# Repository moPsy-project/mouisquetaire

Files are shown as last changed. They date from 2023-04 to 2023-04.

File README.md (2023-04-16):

# Mousquetaire Eurorack Module

> Eurorack Synthesizer module for Audio/CV Adder and Buffered Multiple

## Dependencies

This project uses symbols from the [moPsy-KiCad-resources](https://github.com/moPsy-project/moPsy-KiCad-resources).

## License



This work is licensed under a [Creative Commons Attribution-ShareAlike 4.0 International License](http://creativecommons.org/licenses/by-sa/4.0/).

BY: Stefan Haun (mail@tuxathome.de)

See [LICENSE.txt](LICENSE.txt) for details.

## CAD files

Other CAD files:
Frontpanel/mousquetaire-outline.FCStd
Frontpanel/mousquetaire-outline.dxf

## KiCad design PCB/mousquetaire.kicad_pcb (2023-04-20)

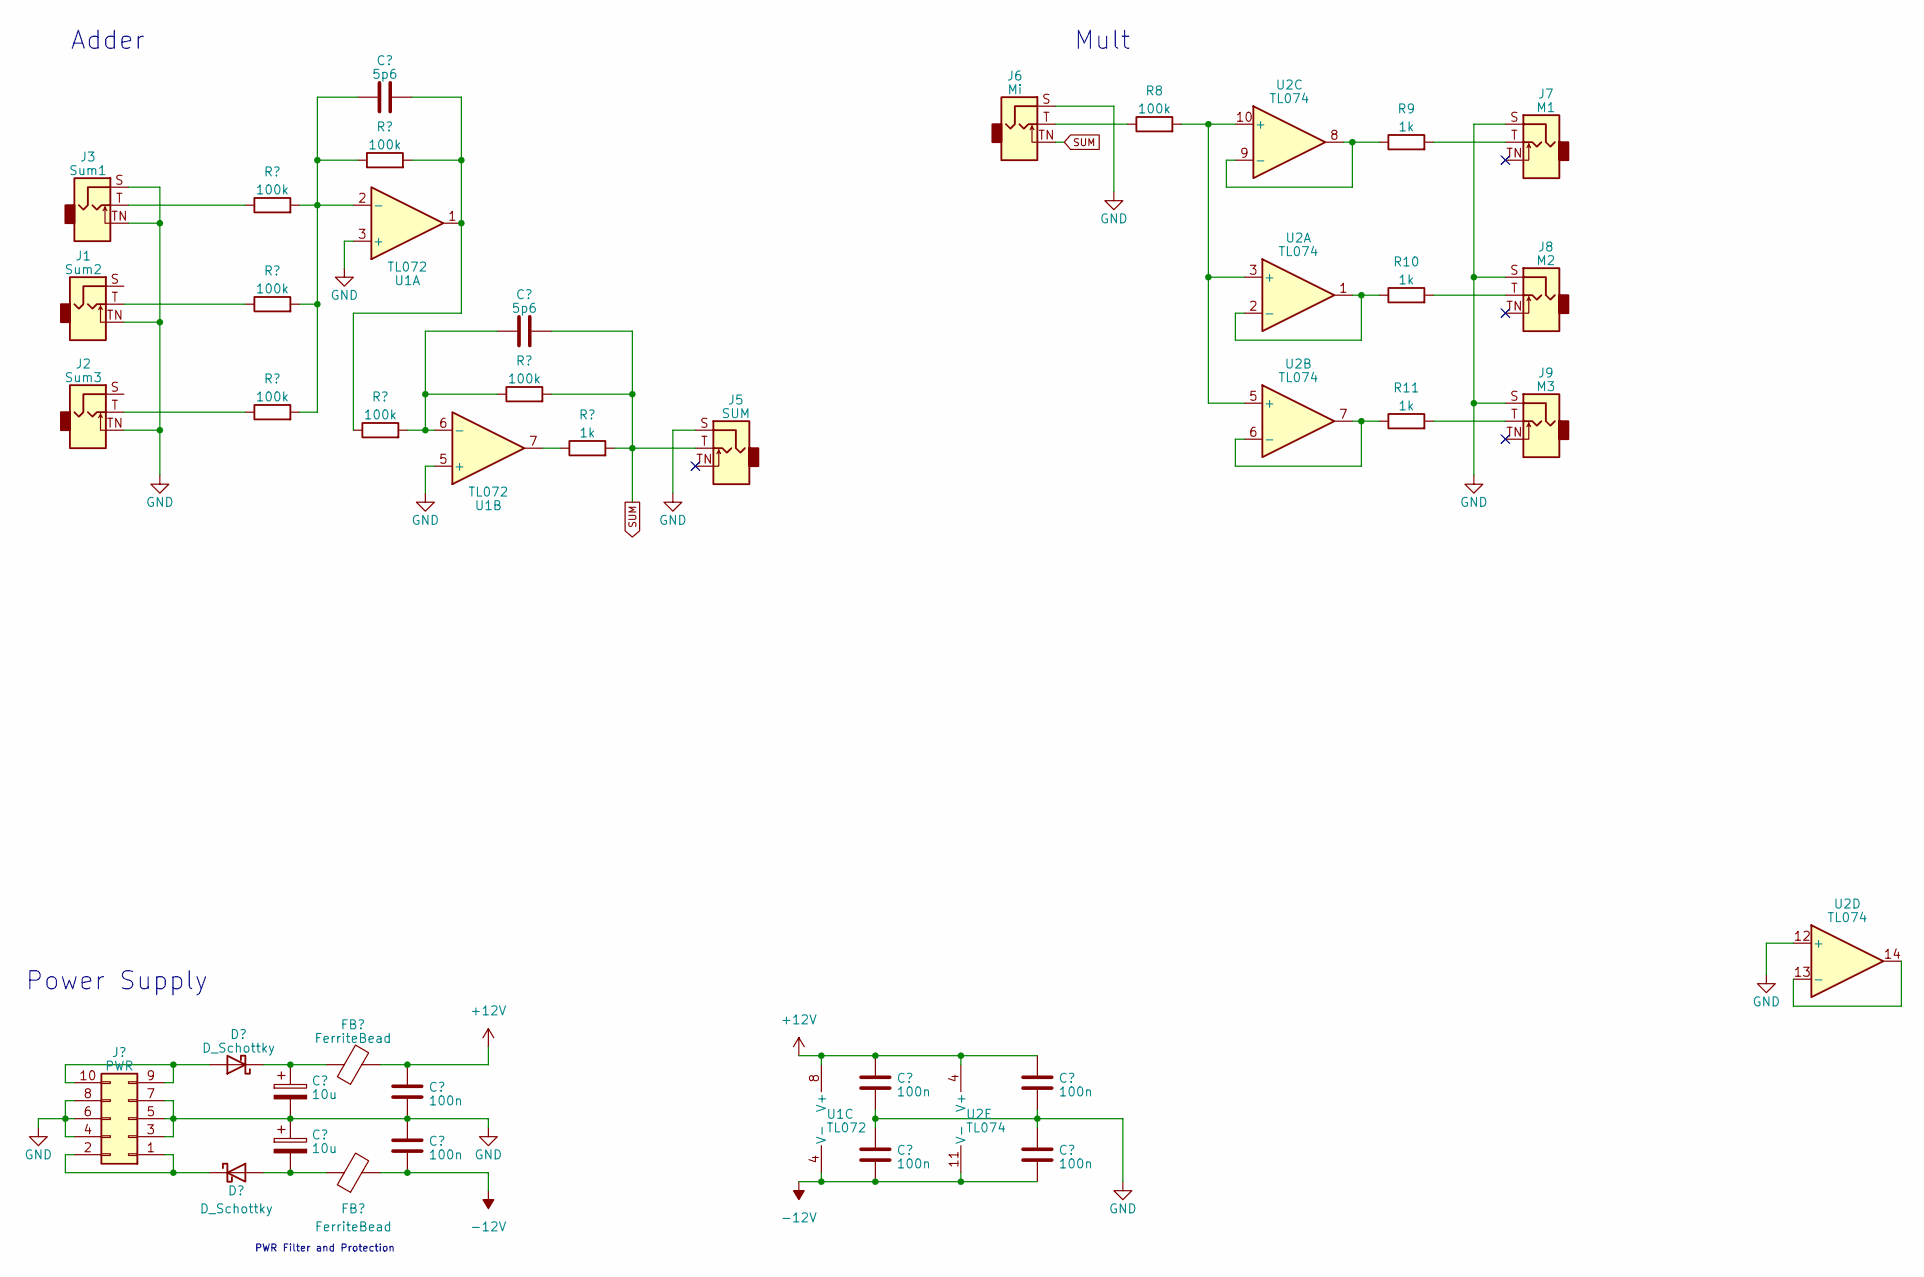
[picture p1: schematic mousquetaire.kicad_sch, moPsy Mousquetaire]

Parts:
C1, C2: 10u; CP_Radial_D4.0mm_P1.50mm
C3, C6: 5p6; C_Disc_D4.3mm_W1.9mm_P5.00mm
C4, C5, C7, C8, C9, C10: 100n; C_Disc_D4.3mm_W1.9mm_P5.00mm
D1, D2: D_Schottky; D_DO-41_SOD81_P7.62mm_Horizontal
FB1, FB2: FerriteBead; FBeadL4D4
J1: Sum2; CLIFF 3.5mm S6 Mono Jack Socket
J2: Sum3; CLIFF 3.5mm S6 Mono Jack Socket
J3: Sum1; CLIFF 3.5mm S6 Mono Jack Socket
J4: PWR; PinHeader_2x05_P2.54mm_Vertical
J5: SUM; CLIFF 3.5mm S6 Mono Jack Socket
J6: Mi; CLIFF 3.5mm S6 Mono Jack Socket
J7: M1; CLIFF 3.5mm S6 Mono Jack Socket
J8: M2; CLIFF 3.5mm S6 Mono Jack Socket
J9: M3; CLIFF 3.5mm S6 Mono Jack Socket
R1, R2, R3, R4, R5, R6, R8: 100k; R_Axial_DIN0207_L6.3mm_D2.5mm_P7.62mm_Horizontal
R7, R9, R10, R11: 1k; R_Axial_DIN0207_L6.3mm_D2.5mm_P7.62mm_Horizontal
U1: TL072; DIP-8_W7.62mm_Socket_LongPads
U2: TL074; DIP-14_W7.62mm_Socket_LongPads

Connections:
+12V: C4.1, C7.1, C9.1, FB1.2, U1.8 (V+), U2.4 (V+)
-12V: C5.2, C8.2, C10.2, FB2.2, U1.4 (V-), U2.11 (V-)
GND: C1.2, C2.1, C4.2, C5.1, C7.2, C8.1, C9.2, C10.1, J1.TN, J2.TN, J3.S, J3.TN, J4.3, J4.4, J4.5, J4.6, J4.7, J4.8, J5.S, J6.S, J7.S, J8.S, J9.S, U1.3 (+), U1.5 (+), U2.12 (+)
unnamed: C3.2, R4.1, R5.2, U1.1
unnamed: D1.2 (A), J4.9, J4.10
unnamed: C1.1, D1.1 (K), FB1.1
unnamed: C2.2, D2.2 (A), FB2.1
unnamed: D2.1 (K), J4.1, J4.2
unnamed: J1.T, R2.1
unnamed: J2.T, R3.1
unnamed: J3.T, R1.1
unnamed: J6.T, R8.1
unnamed: J7.T, R9.2
unnamed: J8.T, R10.2
unnamed: J9.T, R11.2
unnamed: R7.1, U1.7
unnamed: C3.1, R1.2, R2.2, R3.2, R5.1, U1.2 (-)
unnamed: C6.1, R4.2, R6.1, U1.6 (-)
unnamed: R8.2, U2.3 (+), U2.5 (+), U2.10 (+)
unnamed: R10.1, U2.1, U2.2 (-)
unnamed: R11.1, U2.6 (-), U2.7
unnamed: R9.1, U2.8, U2.9 (-)
unnamed: U2.13 (-), U2.14
SUM: C6.2, J5.T, J6.TN, R6.2, R7.2

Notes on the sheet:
Adder
Mult
Power Supply
PWR Filter and Protection

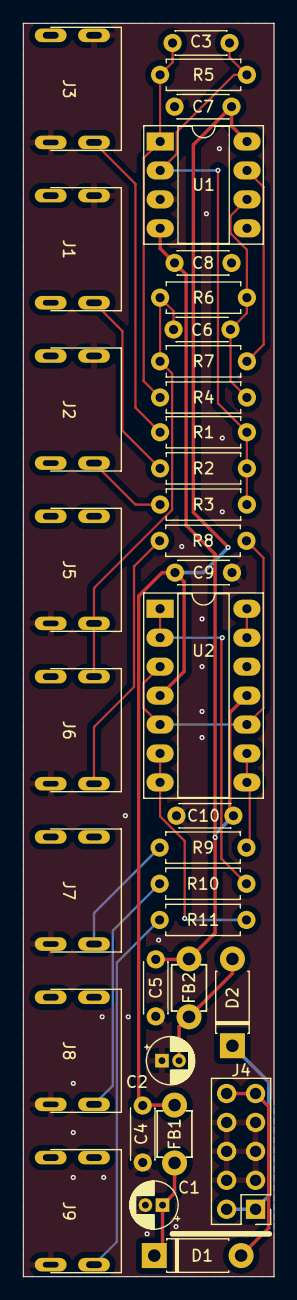
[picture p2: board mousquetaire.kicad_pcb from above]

Board: 2 copper layers, 22.0 x 110.0 mm, 36 parts (0 on the bottom side), 24 nets.

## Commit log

2023-04-16 :see_no_evil: Add gitignore for KiCad project
2023-04-16 :sparkles: Add KiCad project and schematic draft
    [mousquetaire.kicad_sch]
2023-04-16 :sparkles: Add frontpanel outline as FreeCad sketch
    [mousquetaire-outline.FCStd]
2023-04-16 :bento: Add DXF export of outline
    [mousquetaire-outline.dxf]
2023-04-16 :sparkles: Add draft for the PCB layout
    [mousquetaire.kicad_pcb]
2023-04-20 :pencil2: Fix the adder circuit
    [mousquetaire.kicad_sch]
2023-04-20 :pencil2: Add missing changes for the adder fix
    Somehow not everything had been committed for #2. This is the fix. :/
    [mousquetaire.kicad_sch]
2023-04-20 :hammer: Set up project for PCB design
2023-04-20 :art: Improvements to schematic for PCB design
    Mostly interchanging components for easier routing.
    [mousquetaire.kicad_sch]
2023-04-20 :hammer: Adjust layout after fixing the schematic
    [mousquetaire.kicad_pcb]
2023-04-20 :sparkles: Route traces on the PCB
    [mousquetaire.kicad_pcb]
2023-04-20 :hammer: Change power connector to vertical footprint
    [mousquetaire.kicad_sch]
2023-04-20 :hammer: Turn power connector around and adapt to footprint
    Move the power connector so that the red stripe is down.
    [mousquetaire.kicad_pcb]
